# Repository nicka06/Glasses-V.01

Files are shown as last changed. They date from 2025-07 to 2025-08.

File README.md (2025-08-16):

# Glasses-V.01

This repo shows a pair of "AI" glasses that use a microphone, speaker, and microcontroller to allow users to have siri at all times (when on wifi). They'll be able to ask questions, complete tasks, and be more efficient with these glasses. While these glasses have only audio, it is a first step towareds glasses with cameras and more. This is my personal end goal for this project. Just a stepping stone towards more advance glasses work. (Hence the V0.1 repo name). If you have any questions, feel free to reach out. 

Full Glasses Screenshot
PCB Arm Screenshot
Battery Arm Screenshot
PCB Screenshot
Frame Screenshot
Screenshot 2025-08-16 at 12 45 35 PM
Screenshot 2025-08-16 at 12 45 51 PM

|Part |Part Number |# of parts|snapeda link |Price|Actual Link |Total Price|
|---|---|---|---|-----|---|---|
|Microcontroller |ESP32-S3-WROOM-1-N16R8 |1 |https://www.snapeda.com/parts/ESP32-S3-WROOM-1-N16R8/Espressif%20Systems/view-part/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 |6.56 |https://www.digikey.com/en/products/detail/espressif-systems/ESP32-S3-WROOM-1-N16R8/16163954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 |13.12 |
|Microphone |ICS-43434 |1 |https://www.snapeda.com/parts/ICS-43434/TDK%20InvenSense/view-part/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 |2.98 |https://www.digikey.com/en/products/detail/tdk-invensense/ICS-43434/6140298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 |5.96 |
|Amplifier |MAX98357AETE+T |1 |http://snapeda.com/parts/MAX98357AETE%2BT/Analog%20Devices/view-part/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 |3.19 |https://www.digikey.com/en/products/detail/analog-devices-inc-maxim-integrated/MAX98357AETE-T/4936122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 |6.38 |
|Speaker |KDMG151508-05 |1 |https://www.snapeda.com/parts/KDMG151508-05/Kingstate/view-part/?ref=search&t=KDMG151508-05 |2.12 |https://www.digikey.com/en/products/detail/db-unlimited/SM150908-2/9990586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 |4.24 |
|Battery |1570 Lithium Polymer Battery 3.7V 100mAh|1 |https://www.snapeda.com/parts/1570/Adafruit%20Industries/view-part/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 |5.95 |https://www.digikey.com/en/products/detail/adafruit-industries-llc/1570/5054546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 |11.9 |
|Charge Management Controller|MCP73831T-2ACI/OT |1 |https://www.snapeda.com/parts/MCP73831T-2ACI/OT/Microchip%20Technology/view-part/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 |0.76 |https://www.digikey.com/en/products/detail/microchip-technology/MCP73831T-2ACI-OT/964301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 |1.52 |
| |TLV62568DBVR |1 |https://www.snapeda.com/parts/2340901-1/TE%20Connectivity/view-part/?ref=search&t=2340901-1&ab_test_case=b |0.23 |https://www.digikey.com/en/products/detail/texas-instruments/TLV62568DBVR/6588886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 |0.46 |
|USB C Port |2340901-1 |1 |https://www.snapeda.com/parts/2340901-1/TE%20Connectivity/view-part/?ref=search&t=2340901-1&ab_test_case=b |0.7  |https://www.digikey.com/en/products/detail/gct/USB4500-03-0-A/15283206 |1.4 |
|Battery Connector (white) |B2B-PH-K-S (LF)(SN) |1 |https://www.snapeda.com/parts/B2B-PH-K-S%20%28LF%29%28SN%29/JST/view-part/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 |0.1  |https://www.digikey.com/en/products/detail/jst-sales-america-inc/B2B-XH-A/1651045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 |0.2 |
|Manual Switch |PCM12SMTR |1 |https://www.snapeda.com/parts/PCM12SMTR/Littelfuse%2FC%26K/view-part/?ref=search&t=PCM12SMTR&ab_test_case=b |0.8  |https://www.snapeda.com/parts/PCM12SMTR/Littelfuse%2FC%26K/view-part/?ref=search&t=PCM12SMTR&ab_test_case=b |1.6 |
|LED Blue Light |LTST-C191TBKT |1 |https://www.snapeda.com/parts/LTST-C191TBKT/Lite-On%20Electronics/view-part/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 |0.24 |https://www.digikey.com/en/products/detail/liteon/LTST-C191TBKT/388530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 |0.48 |
|LED Red Light |LTST-C191KRKT |1 |https://www.snapeda.com/parts/LTST-C191KRKT/Lite-On%20Inc./view-part/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 |0.15 |https://www.digikey.com/en/products/detail/liteon/LTST-C191KRKT/386837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 |0.3 |
|5.1k Resistor |ERA-3ARB512V |3 |https://www.snapeda.com/parts/ERA-3ARB512V/Panasonic/view-part/?ref=search&t=ERA-3ARB512V&ab_test_case=b |0.35 |https://www.digikey.com/en/products/detail/panasonic-electronic-components/ERA-3ARB512V/3073669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 |2.1 |
|10k resistor |CR0603AFX-1002EAS |2 |https://www.snapeda.com/parts/CR0603AFX-1002EAS/Bourns/view-part/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 |0.1  |https://www.digikey.com/en/products/detail/bourns-inc/CR0603AFX-1002EAS/10240117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 |0.4 |
|220hms Resistor |WK73R1JTTD2200F |2 |https://www.snapeda.com/parts/WK73R1JTTD2200F/KOA%20Speer/view-part/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 |0.12 |https://www.mouser.com/ProductDetail/KOA-Speer/WK73R1JTTD2200F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 |0.48 |
|100nf capacitor |885012206071 |4 |https://www.snapeda.com/parts/885012206071/W%C3%BCrth%20Elektronik/view-part/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 |0.1  |https://www.digikey.com/en/products/detail/w%C3%BCrth-elektronik/885012206071/5453844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 |0.8 |
|4.7u capitor |CL10A475KA8NQNC |1 |https://www.snapeda.com/parts/CL10A475KA8NQNC/Samsung/view-part/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 |0.23 |https://www.mouser.com/ProductDetail/Samsung-Electro-Mechanics/CL10A475KA8NQNC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 |0.46 |
|10uf capictor |GRM188R61A106MAALD |2 |https://www.snapeda.com/parts/GRM188R61A106MAALD/Murata/view-part/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 |0.22 |https://www.digikey.com/en/products/detail/murata-electronics/GRM188R61A106MAALD/4905335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 |0.88 |
|22uf capictor |C1608X5R0J226M080AC |1 |https://www.snapeda.com/parts/C1608X5R0J226M080AC/TDK/view-part/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 |0.27 |https://www.digikey.com/en/products/detail/tdk-corporation/C1608X5R0J226M080AC/2792254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 |0.54 |
|2.2 inductor |DFE252012F-2R2M=P2 |1 |https://www.snapeda.com/parts/DFE252012F-2R2M%3DP2/Murata/view-part/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 |0.24 |https://www.digikey.com/en/products/detail/murata-electronics/DFE252012F-2R2M-P2/5812591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 |0.48 |
|ESD Protector |TPD2E001DRLRG4 |1 |https://www.snapeda.com/parts/TPD2E001DRLRG4/Texas%20Instruments/view-part/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 |0.77 |https://www.digikey.com/en/products/detail/texas-instruments/TPD2E001DRLRG4/1907452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 |1.54 |
|1u capitor |885012206026 |1 |https://www.snapeda.com/parts/885012206026/W%C3%BCrth%20Elektronik/view-part/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 |0.27 |https://www.digikey.com/en/products/detail/w%C3%BCrth-elektronik/885012206026/5453800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 |0.54 |
|Switch Button |TL3315NF160Q |1 |https://www.snapeda.com/parts/TL3315NF160Q/E-Switch/view-part/?ref=search&t=tl3315nf160Q |0.15 |https://www.digikey.com/en/products/detail/e-switch/TL3315NF160Q/1870395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 |0.3 |
|3d Printing filament |N/A |1 |https://www.amazon.com/eSUN-Filament-Printing-Printer-Designed/dp/B0DGQBMJMK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|11.39|https://www.amazon.com/eSUN-Filament-Printing-Printer-Designed/dp/B0DGQBMJMK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|11.39 |
|PCB |N/A |1 |N/A |2 |N/A |2 |
| | | | | | |69.47 |
                                                                                                                                                                                                                                                                                    |56.08      |

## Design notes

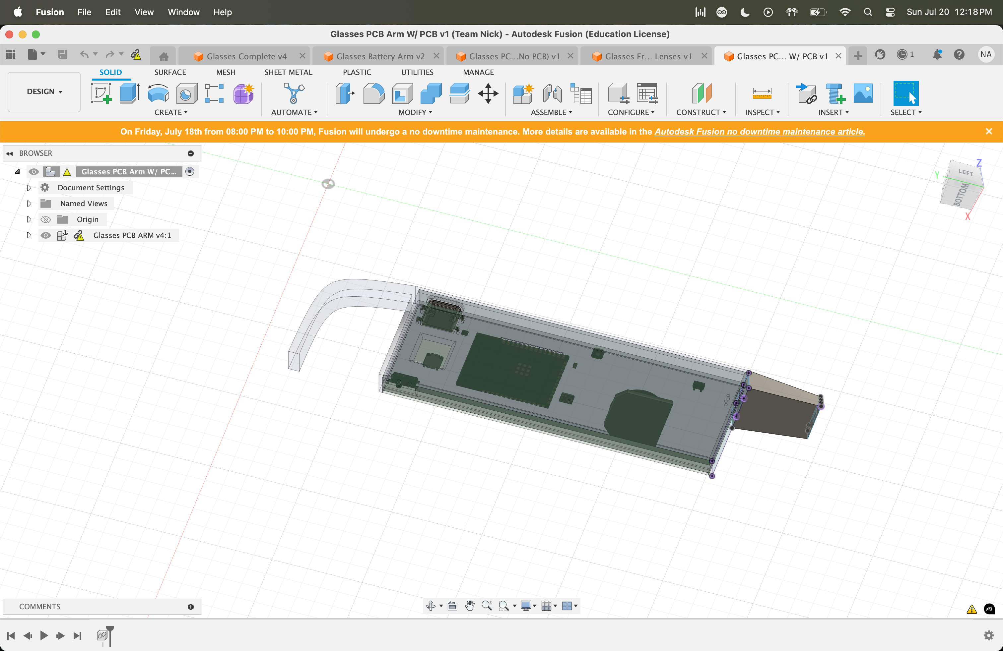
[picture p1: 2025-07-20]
production/pics/Screenshot 2025-07-20 at 12.18.14 PM.png

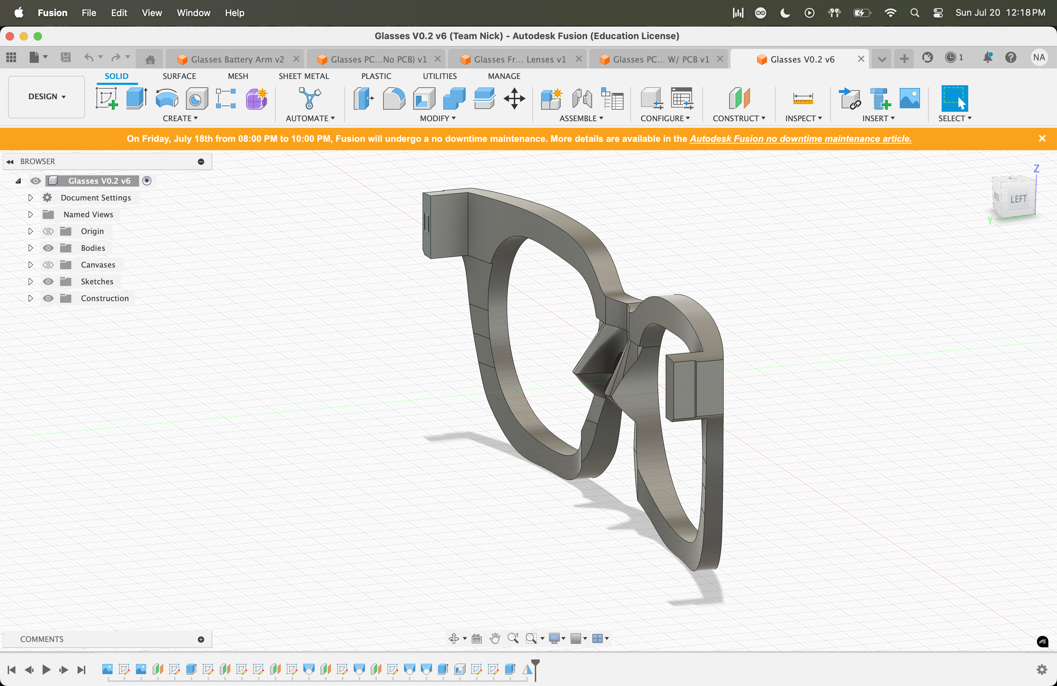
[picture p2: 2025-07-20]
production/pics/Screenshot 2025-07-20 at 12.18.28 PM.png

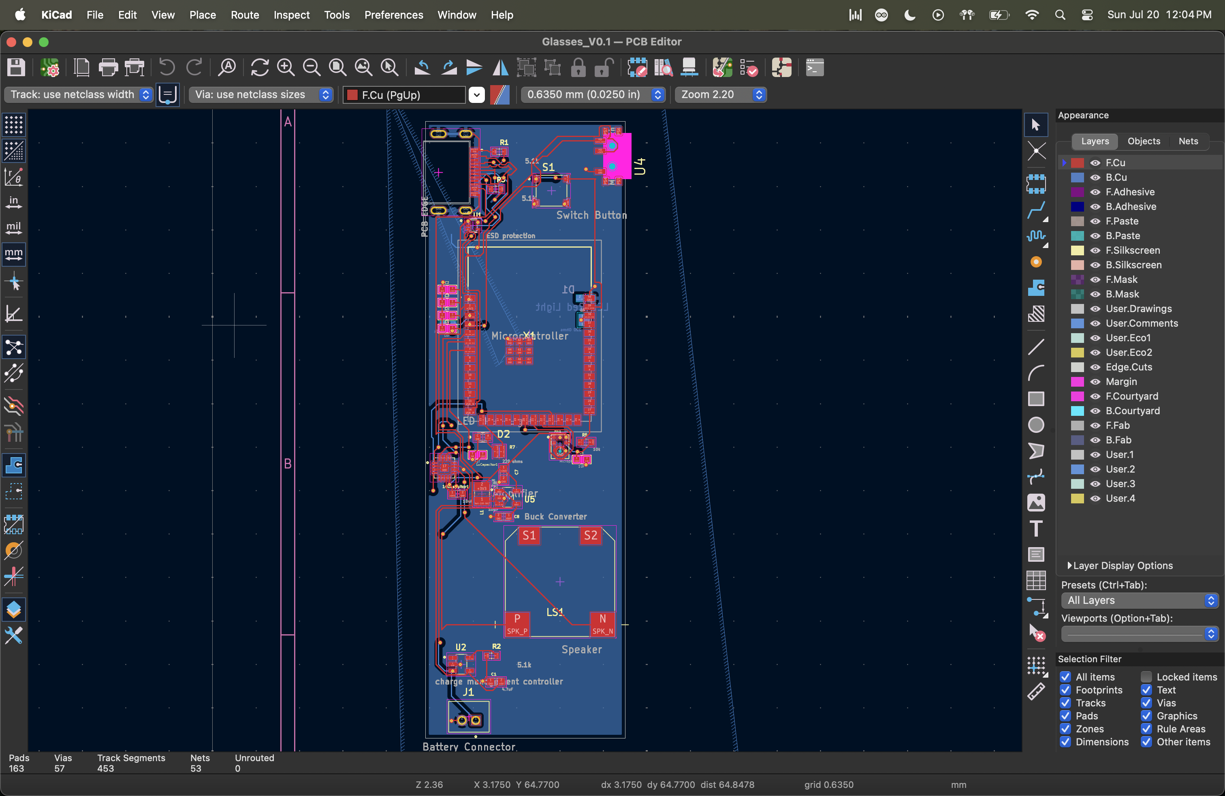
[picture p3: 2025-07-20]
production/pics/Screenshot 2025-07-20 at 12.04.41 PM.png

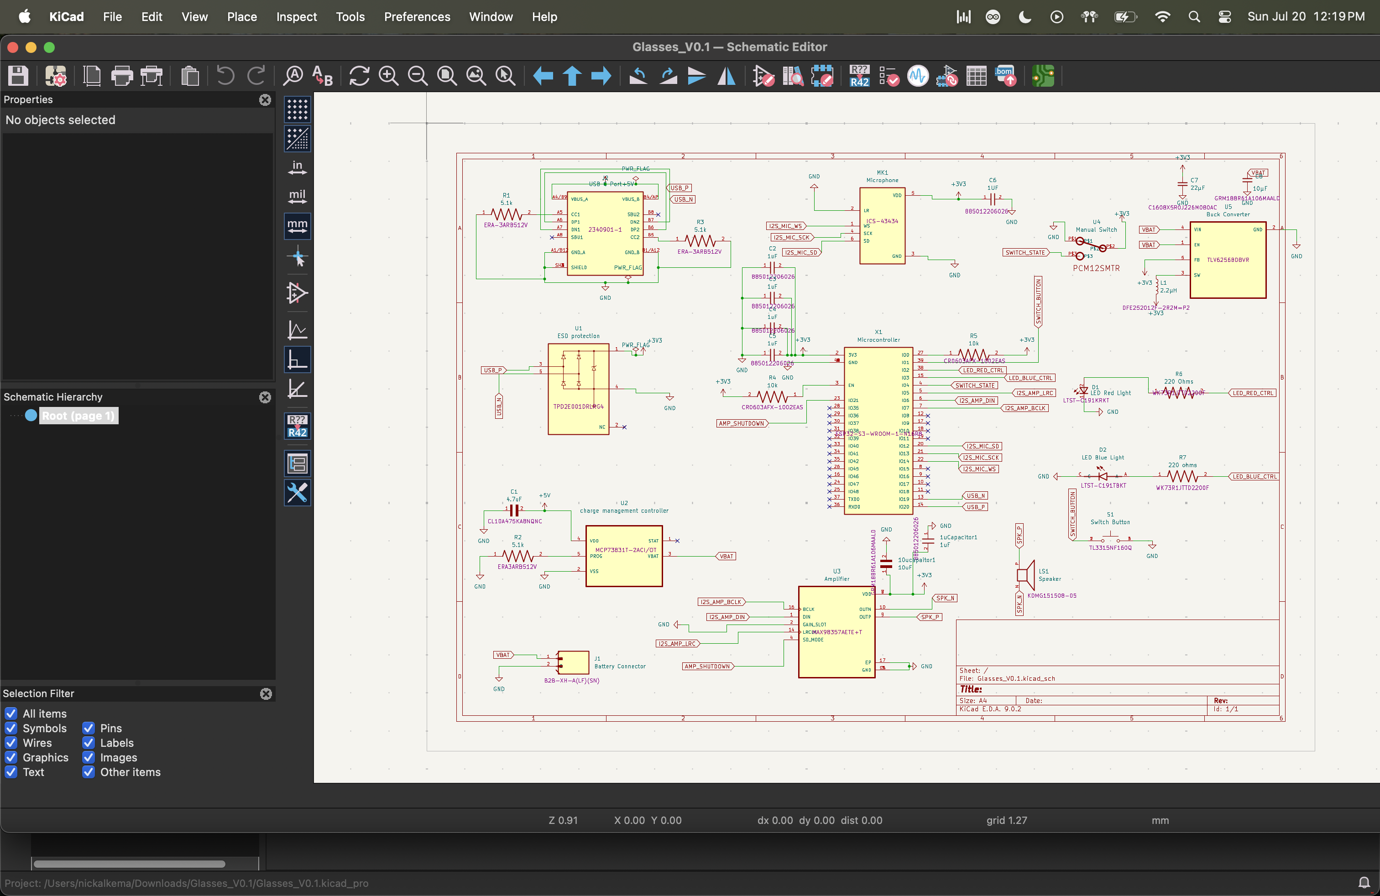
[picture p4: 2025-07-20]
production/pics/Screenshot 2025-07-20 at 12.19.34 PM.png

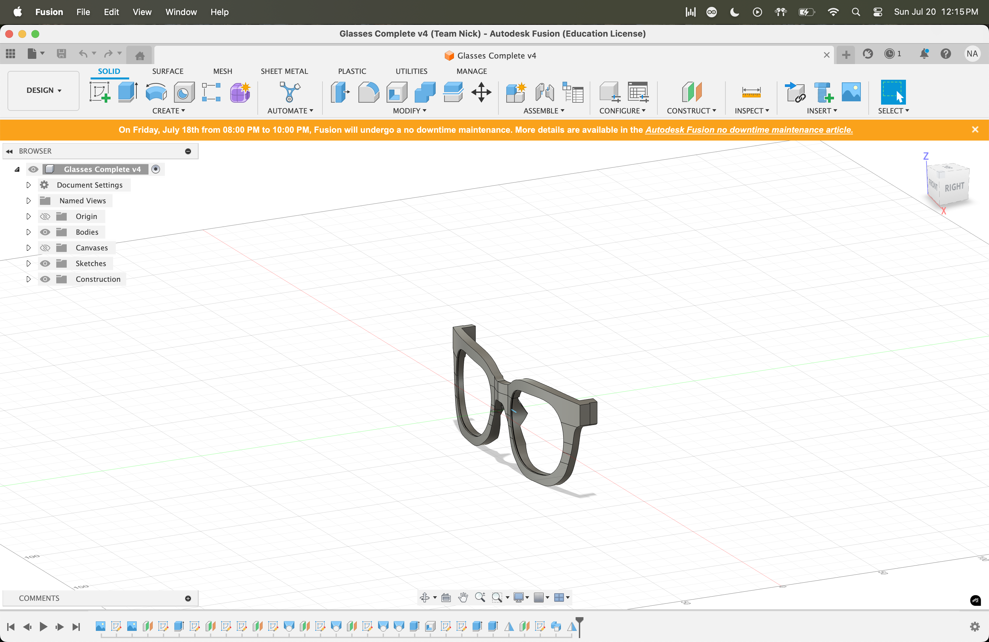
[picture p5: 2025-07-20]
production/pics/Screenshot 2025-07-20 at 12.15.24 PM.png

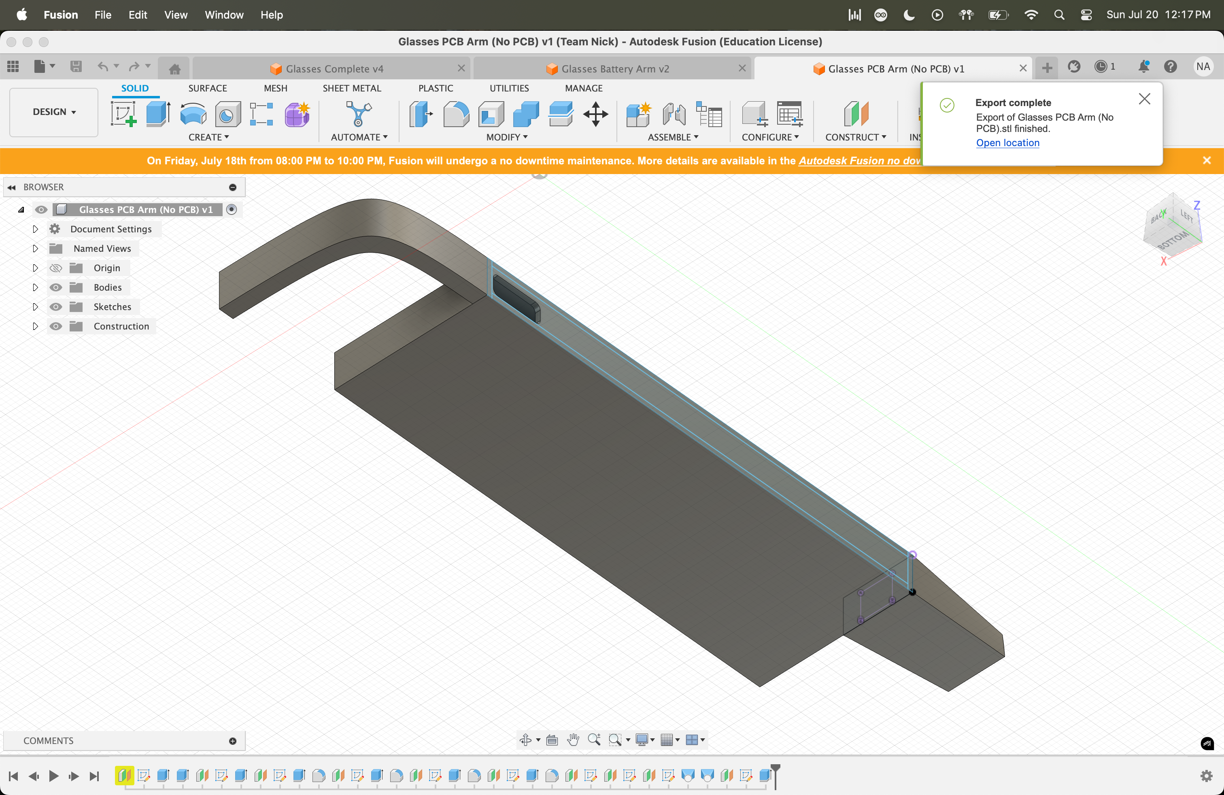
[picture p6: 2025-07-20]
production/pics/Screenshot 2025-07-20 at 12.17.30 PM.png

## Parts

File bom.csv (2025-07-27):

Part | Part Number | # of parts | snapeda link | Price | Actual Link | Total Price
Microcontroller | ESP32-S3-WROOM-1-N16R8 | 1 | https://www.snapeda.com/parts/ESP32-S3-WROOM-1-N16R8/Espressif%20Systems/view-part/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 | 6.56 | https://www.digikey.com/en/products/detail/espressif-systems/ESP32-S3-WROOM-1-N16R8/16163954?gad_source=1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 | 13.12
Microphone | ICS-43434 | 1 | https://www.snapeda.com/parts/ICS-43434/TDK%20InvenSense/view-part/?t=ICS-43434&con_ref=None | 2.98 | https://www.digikey.com/en/products/detail/tdk-invensense/ICS-43434/6140298 | 5.96
Amplifier | MAX98357AETE+T | 1 | http://snapeda.com/parts/MAX98357AETE%2BT/Analog%20Devices/view-part/?t=MAX98357AETE%2BT&ab_test_case=b | 3.19 | https://www.digikey.com/en/products/detail/analog-devices-inc-maxim-integrated/MAX98357AETE-T/4936122 | 6.38
Speaker | KDMG151508-05 | 1 | https://www.snapeda.com/parts/KDMG151508-05/Kingstate/view-part/?ref=search&t=KDMG151508-05 | 2.12 | https://www.digikey.com/en/products/detail/db-unlimited/SM150908-2/9990586?gad_source=1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 | 4.24
Battery | 1570 Lithium Polymer Battery 3.7V 100mAh | 1 | https://www.snapeda.com/parts/1570/Adafruit%20Industries/view-part/?ab_test_case=b | 5.95 | https://www.digikey.com/en/products/detail/adafruit-industries-llc/1570/5054546 | 11.9
Charge Management Controller | MCP73831T-2ACI/OT | 1 | https://www.snapeda.com/parts/MCP73831T-2ACI/OT/Microchip%20Technology/view-part/?t=MCP73831&ab_test_case=b | 0.76 | https://www.digikey.com/en/products/detail/microchip-technology/MCP73831T-2ACI-OT/964301 | 1.52
 | TLV62568DBVR | 1 | https://www.snapeda.com/parts/2340901-1/TE%20Connectivity/view-part/?t=2340901-1&ab_test_case=b | 0.23 | https://www.digikey.com/en/products/detail/texas-instruments/TLV62568DBVR/6588886 | 0.46
USB C Port | 2340901-1 | 1 | https://www.snapeda.com/parts/2340901-1/TE%20Connectivity/view-part/?t=2340901-1&ab_test_case=b | 0.7 | https://www.digikey.com/en/products/detail/gct/USB4500-03-0-A/15283206 | 1.4
Battery Connector (white) | B2B-PH-K-S (LF)(SN) | 1 | https://www.snapeda.com/parts/B2B-PH-K-S%20%28LF%29%28SN%29/JST/view-part/?t=B2B-PH-K-S&ab_test_case=b | 0.1 | https://www.digikey.com/en/products/detail/jst-sales-america-inc/B2B-XH-A/1651045?gad_source=1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 | 0.2
Manual Switch | PCM12SMTR | 1 | https://www.snapeda.com/parts/PCM12SMTR/Littelfuse%2FC%26K/view-part/?t=PCM12SMTR&ab_test_case=b | 0.8 | https://www.snapeda.com/parts/PCM12SMTR/Littelfuse%2FC%26K/view-part/?t=PCM12SMTR&ab_test_case=b | 1.6
LED Blue Light | LTST-C191TBKT | 1 | https://www.snapeda.com/parts/LTST-C191TBKT/Lite-On%20Electronics/view-part/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 | 0.24 | https://www.digikey.com/en/products/detail/liteon/LTST-C191TBKT/388530 | 0.48
LED Red Light | LTST-C191KRKT | 1 | https://www.snapeda.com/parts/LTST-C191KRKT/Lite-On%20Inc./view-part/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 | 0.15 | https://www.digikey.com/en/products/detail/liteon/LTST-C191KRKT/386837 | 0.3
5.1k Resistor | ERA-3ARB512V | 3 | https://www.snapeda.com/parts/ERA-3ARB512V/Panasonic/view-part/?t=ERA-3ARB512V&ab_test_case=b | 0.35 | https://www.digikey.com/en/products/detail/panasonic-electronic-components/ERA-3ARB512V/3073669 | 2.1
10k resistor | CR0603AFX-1002EAS | 2 | https://www.snapeda.com/parts/CR0603AFX-1002EAS/Bourns/view-part/?t=CR0603AFX-1002EAS&ab_test_case=b | 0.1 | https://www.digikey.com/en/products/detail/bourns-inc/CR0603AFX-1002EAS/10240117 | 0.4
220hms Resistor | WK73R1JTTD2200F | 2 | https://www.snapeda.com/parts/WK73R1JTTD2200F/KOA%20Speer/view-part/?t=WK73R1JTTD2200F&ab_test_case=b | 0.12 | https://www.mouser.com/ProductDetail/KOA-Speer/WK73R1JTTD2200F?qs=xhbEVWpZdWcwQMv%2FxntCbQ%3D%3D | 0.48
100nf capacitor | 885012206071 | 4 | https://www.snapeda.com/parts/885012206071/W%C3%BCrth%20Elektronik/view-part/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 | 0.1 | https://www.digikey.com/en/products/detail/w%C3%BCrth-elektronik/885012206071/5453844 | 0.8
4.7u capitor | CL10A475KA8NQNC | 1 | https://www.snapeda.com/parts/CL10A475KA8NQNC/Samsung/view-part/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 | 0.23 | https://www.mouser.com/ProductDetail/Samsung-Electro-Mechanics/CL10A475KA8NQNC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 | 0.46
10uf capictor | GRM188R61A106MAALD | 2 | https://www.snapeda.com/parts/GRM188R61A106MAALD/Murata/view-part/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 | 0.22 | https://www.digikey.com/en/products/detail/murata-electronics/GRM188R61A106MAALD/4905335 | 0.88
22uf capictor | C1608X5R0J226M080AC | 1 | https://www.snapeda.com/parts/C1608X5R0J226M080AC/TDK/view-part/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 | 0.27 | https://www.digikey.com/en/products/detail/tdk-corporation/C1608X5R0J226M080AC/2792254 | 0.54
2.2 inductor | DFE252012F-2R2M=P2 | 1 | https://www.snapeda.com/parts/DFE252012F-2R2M%3DP2/Murata/view-part/?t=DFE252012F-2R2M%3DP2&ab_test_case=b | 0.24 | https://www.digikey.com/en/products/detail/murata-electronics/DFE252012F-2R2M-P2/5812591 | 0.48
ESD Protector | TPD2E001DRLRG4 | 1 | https://www.snapeda.com/parts/TPD2E001DRLRG4/Texas%20Instruments/view-part/?t=TPD2E001DRLR&ab_test_case=b | 0.77 | https://www.digikey.com/en/products/detail/texas-instruments/TPD2E001DRLRG4/1907452 | 1.54
1u capitor | 885012206026 | 1 | https://www.snapeda.com/parts/885012206026/W%C3%BCrth%20Elektronik/view-part/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 | 0.27 | https://www.digikey.com/en/products/detail/w%C3%BCrth-elektronik/885012206026/5453800 | 0.54
Switch Button | TL3315NF160Q | 1 | https://www.snapeda.com/parts/TL3315NF160Q/E-Switch/view-part/?ref=search&t=tl3315nf160Q | 0.15 | https://www.digikey.com/en/products/detail/e-switch/TL3315NF160Q/1870395 | 0.3
 |  |  |  |  |  | 56.08

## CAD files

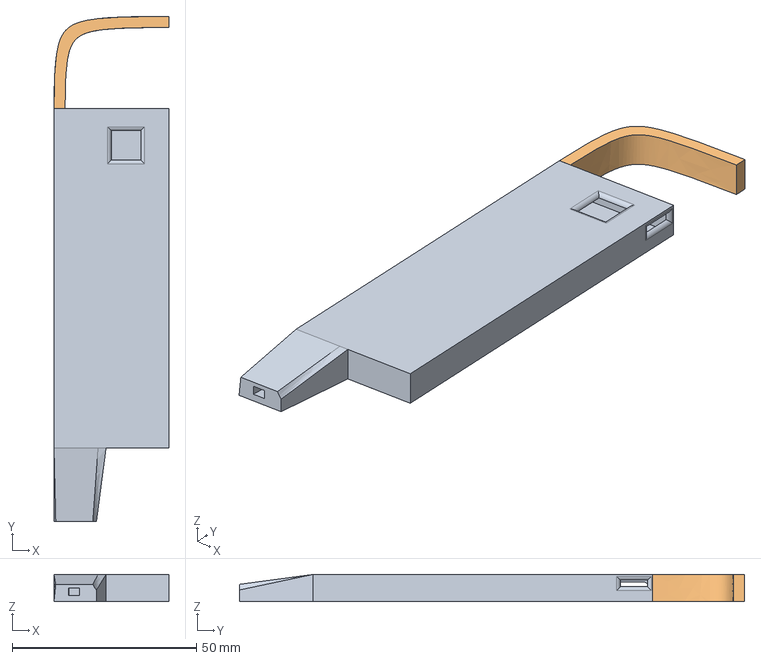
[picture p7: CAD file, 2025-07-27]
cad/Glasses PCB Arm (No PCB) v1.step
31.2 x 137.2 x 7.35 mm

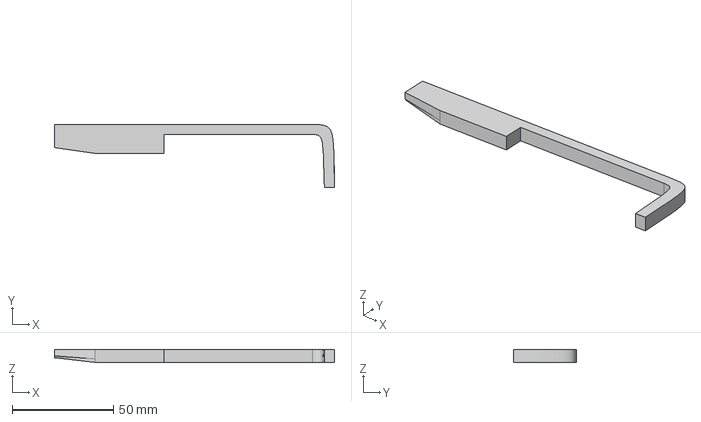
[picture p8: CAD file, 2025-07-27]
cad/Glasses Battery Arm v2.step
138.2 x 31.2 x 6.30 mm

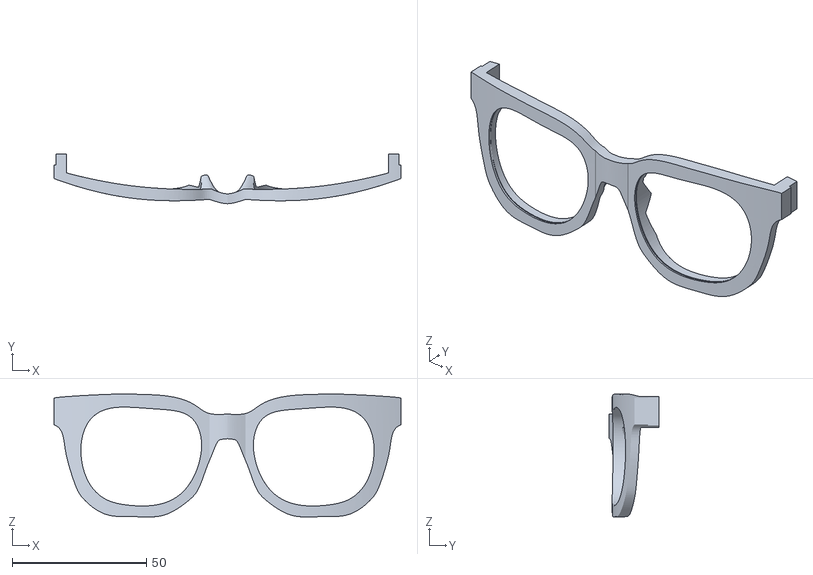
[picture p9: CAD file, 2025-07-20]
production/cad/Glasses Frames.stl
129.5 x 18.5 x 45.9

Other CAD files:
production/cad/Glasses PCB Arm (No PCB).stl
production/cad/Glasses Battery Arm.stl

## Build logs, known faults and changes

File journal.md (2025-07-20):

title: "Audio Glasses"

author: "Nick"

description: "Smart glasses that connect to wifi and allow you to essentially use smart siri on your glasses"

created_at: "2024-07-18"

Time Spent: 30 ish hours (maybe more tbh if you consider research as this was one of my first hardware projects ever)

7/18/2025

--Unforunately, I did not read through the requirements and only sumbitted a hackpad thus far which led me to believe there was no journal portion. Thus, when I'm nearing the end of the project, I finally decide to make the journal. 
Although this is a bit disappointing, I'll do my best to recall what I have done thus far and lay it out in chronolocial order. Then, I'll add my future journals here as well. 

Beginning: (10 ish hours)

I started off this project by consulting with chatgpt on a parts list. It started off with a fairly comprehensive list of things that I'll need. Then, I went into snapeda the online website to browse all the parts. This was about a days worth
of work. I know it seems like not that much but this is my "first" hardware project (besides the hackpad that I did which was basically laid out for me in a step by step guide). Also as a side note, beginner projects are so important because I 
don't feel like I could have done any of this without that beginner project.

The next thing I started to do was lay out the schematic. Again, a lot of time was spent consulting with google, the datasheets, and google. It took a lot of finesse and mind numbing work but I was eventually able to get it.
I would estimate just this process took quite a while. It's worth mentioning that I spent a decent chunk of time assembling and modifying the symbols. They were very finicky. The footprint's were also a pain to do.

Middle: (another 8 ish hours)

Once I completed the schematic, I began working on the actual pcb design which was a HUGE pain. I learned that making small pcbs is not a fun process at all. Additioanlly, it was my first time doing it all by myself so add that to the 
mix and I was in for a disaster. I had to restart 3-4 times and it probably took 3-4 days in total to actually get it done. 

Finish Line: ( 12 ish hours)

Finally, I began working on the cad part of the project. In my opinion, this was the part of the project that I had the most fun with. The first thing that I did was download some images of photos, looked up the
size of a typical glasses frame, and then I started to sketch out the outline of the glasses frame. I continued to do this until I was able to complete the glasses frame (with the inside of the glasses hollowed
out for the wires to run through the frames). Once I finished that, I began working on the sides of the frames. The sides were finicky as well as I had to first model around the pcb/battery and then actually create 
the strucuture of glasses. It's worth acknowledging that in this iteration, I made the glasses fit around teh hardware if that makes sense. (So the glasses shape/fit will almost certainly not be ideal. It's my goal 
that when I begin working on this project next time, I do the opposite. I start with a really nice frame and shape for glasses and then work on the hardware to make it fit within the nice frame and size. Now, what I have
left to do as I'm writing this is to upload all of the information to the github, spend some time to slice some of the hardware so that I can assemble it once I get the components and then begin working on the firmware tommorow. 
I have a feeling that the firmware won't be that bad (famous last words). In any case, I'll give that a shot and upload all of that information tomorrow. (Also for the images, I'll post those all at the end). 

7/18/2025 (1.5 hours)

Today, I continued to look through the work that I've done this far to confirm what I wanted to do with the firmware exactly. I came up with teh exact processes that I wanted to use and now that I have that, I started to work on the firmware. Tomorrow, I'll finish the rest of the firmware and submit the project.

7/19/2025 (2-3 hrs)

Today I worked on the firmware and completed that. Then, I started to build out the repository to have all of the information and content that I've been working on for the last few weeks be displayed in this repo. That way, I'd be able to submit to highway later in the day.

Screenshot 2025-07-20 at 12 04 41 PM
Screenshot 2025-07-20 at 12 15 24 PM
Screenshot 2025-07-20 at 12 17 02 PM
Screenshot 2025-07-20 at 12 17 30 PM
Screenshot 2025-07-20 at 12 17 45 PM
Screenshot 2025-07-20 at 12 18 14 PM
Screenshot 2025-07-20 at 12 18 28 PM
Screenshot 2025-07-20 at 12 19 34 PM

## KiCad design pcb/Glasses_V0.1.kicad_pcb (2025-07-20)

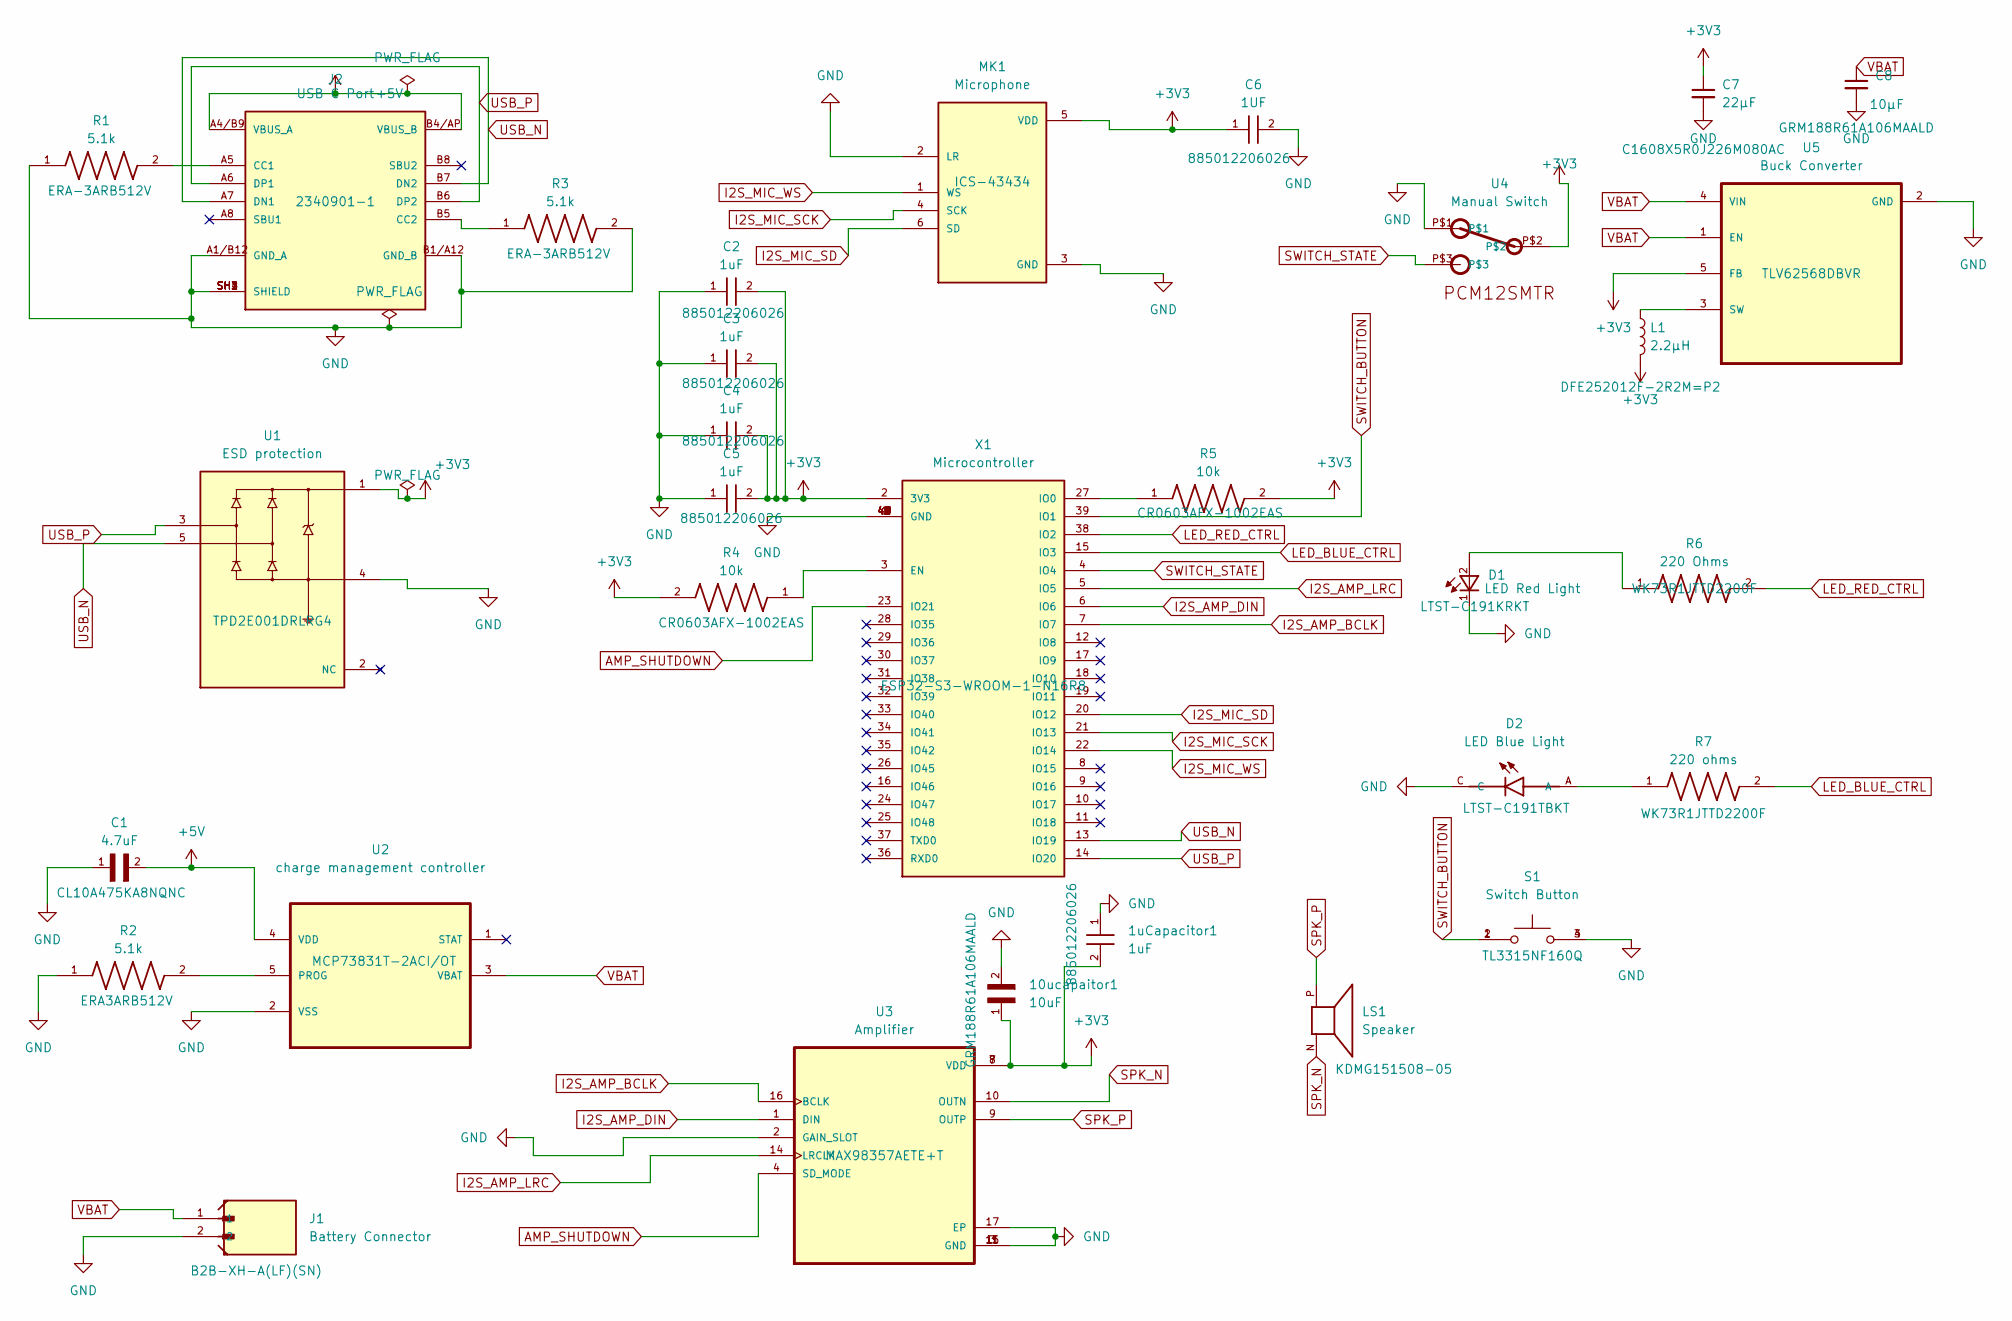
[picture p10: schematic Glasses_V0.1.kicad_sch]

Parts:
1uCapacitor1: 1uF; WCAP-CSGP_0603_R
10ucapaitor1: 10uF; CAPC1608X95N; DigiKey_Part_Number 490-12734-2-ND
C1: 4.7uF; CAPC1608X100N
C2, C3, C4, C5: 1uF; WCAP-CSGP_0603_R
C6: 1UF; WCAP-CSGP_0603_R
C7: 22µF; CAPC1608X100N
C8: 10µF; CAPC1608X95N
D1: LED Red Light; 0603; DigiKey_Part_Number 160-1447-2-ND
D2: LED Blue Light; LEDC1608X65N; DigiKey_Part_Number 160-1647-2-ND
J1: Battery Connector; JST_B2B-PH-K-S_LF__SN_
J2: USB C Port; TE_2340901-1; PARTREV A
L1: 2.2µH; INDC2520X120N
LS1: Speaker; SPKR_KDMG151508-05; PARTREV 1.1
MK1: Microphone; MIC_ICS-43434
R1, R2, R3: 5.1k; RES_ERA3ARB512V; PARTREV 3/1/2020
R4, R5: 10k; RESC1608X55N
R6: 220 Ohms; RESC0816X55N
R7: 220 ohms; RESC0816X55N
S1: Switch Button; SW_TL3315NF160Q; PARTREV B
U1: ESD protection; SOTFL50P160X60-5N; PARTREV I
U2: charge management controller; SOT95P280X145-5N; MPN MCP73831T-2ACI/OT
U3: Amplifier; QFN50P300X300X80-17N
U4: Manual Switch; PCM12SMTR
U5: Buck Converter; SOT95P280X145-5N
X1: Microcontroller; ESP32S3WROOM1N8R2; MANUFACTURER_PART_NUMBER ESP32-S3-WROOM-1-N16R8

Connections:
+3V3: 1uCapacitor1.2, 10ucapaitor1.1, C2.2, C3.2, C4.2, C5.2, C6.1, C7.1, L1.2, MK1.5 (VDD), R4.2, R5.2, U1.1, U3.7 (VDD), U3.8 (VDD), U4.P$2, U5.5 (FB), X1.2 (3V3)
+5V: C1.2, J2.A4/B9 (VBUS_A), J2.B4/AP (VBUS_B), U2.4 (VDD)
AMP_SHUTDOWN: U3.4 (SD_MODE), X1.23 (IO21)
GND: 1uCapacitor1.1, 10ucapaitor1.2, C1.1, C2.1, C3.1, C4.1, C5.1, C6.2, C7.2, C8.2, D1.1, D2.C, J1.2, J2.A1/B12 (GND_A), J2.B1/A12 (GND_B), J2.SH1 (SHIELD), J2.SH2 (SHIELD), J2.SH3 (SHIELD), J2.SH4 (SHIELD), MK1.2 (LR), MK1.3 (GND), R1.1, R2.1, R3.2, S1.3, S1.4, U1.4, U2.2 (VSS), U3.2 (GAIN_SLOT), U3.3 (GND), U3.11 (GND), U3.15 (GND), U3.17 (EP), U4.P$1, U5.2 (GND), X1.1 (GND), X1.40 (GND), X1.41 (GND), X1.42 (GND), X1.43 (GND), X1.44 (GND), X1.45 (GND), X1.46 (GND), X1.47 (GND), X1.48 (GND), X1.49 (GND)
I2S_AMP_BCLK: U3.16 (BCLK), X1.7 (IO7)
I2S_AMP_DIN: U3.1 (DIN), X1.6 (IO6)
I2S_AMP_LRC: U3.14 (LRCLK), X1.5 (IO5)
I2S_MIC_SCK: MK1.4 (SCK), X1.21 (IO13)
I2S_MIC_SD: MK1.6 (SD), X1.20 (IO12)
I2S_MIC_WS: MK1.1 (WS), X1.22 (IO14)
LED_BLUE_CTRL: R7.2, X1.15 (IO3)
LED_RED_CTRL: R6.2, X1.38 (IO2)
unnamed: D1.2, R6.1
unnamed: D2.A, R7.1
unnamed: J2.A5 (CC1), R1.2
unnamed: J2.B5 (CC2), R3.1
unnamed: R2.2, U2.5 (PROG)
unnamed: L1.1, U5.3 (SW)
unnamed: R4.1, X1.3 (EN)
unnamed: R5.1, X1.27 (IO0)
SPK_N: LS1.N, U3.10 (OUTN)
SPK_P: LS1.P, U3.9 (OUTP)
SWITCH_BUTTON: S1.1, S1.2, X1.39 (IO1)
SWITCH_STATE: U4.P$3, X1.4 (IO4)
USB_N: J2.A7 (DN1), J2.B7 (DN2), U1.5, X1.13 (IO19)
USB_P: J2.A6 (DP1), J2.B6 (DP2), U1.3, X1.14 (IO20)
VBAT: C8.1, J1.1, U2.3 (VBAT), U5.1 (EN), U5.4 (VIN)

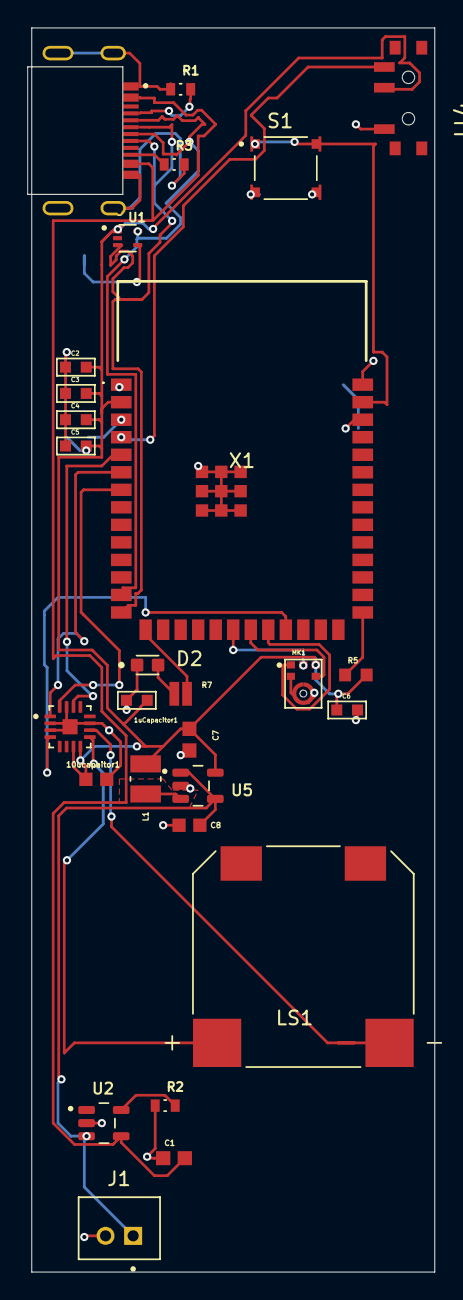
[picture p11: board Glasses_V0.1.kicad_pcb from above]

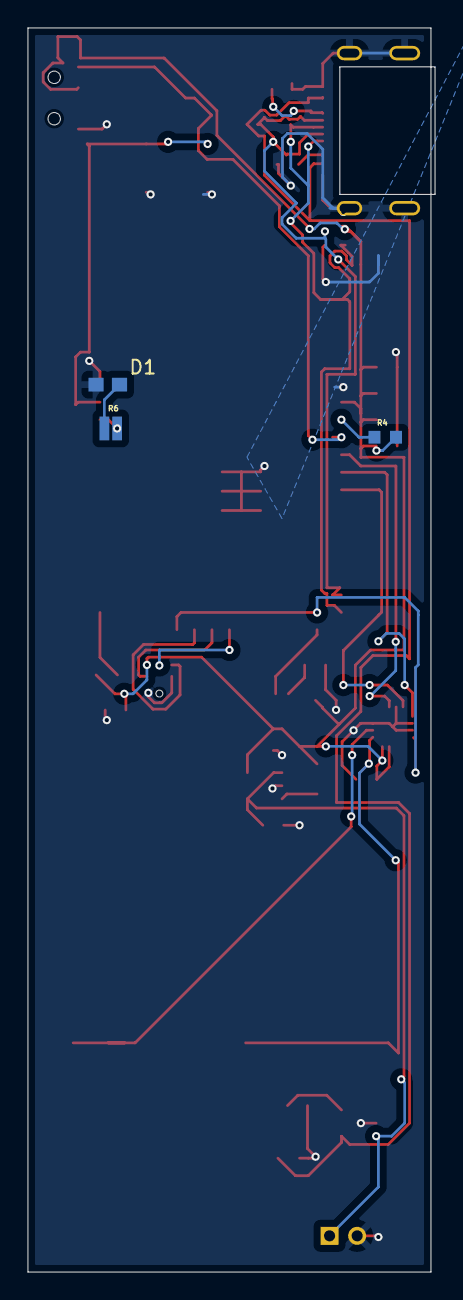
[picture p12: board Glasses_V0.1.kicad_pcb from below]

Board: 2 copper layers, 29.2 x 90.2 mm, 31 parts (3 on the bottom side), 27 nets.

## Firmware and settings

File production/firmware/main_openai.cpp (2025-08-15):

#include <Arduino.h>
#include "hardware_pins.h"
#include <WiFi.h>
#include <HTTPClient.h>
#include <ArduinoJson.h>
#include "driver/i2s.h"
#include <base64.h>

// --- WiFi Configuration ---
const char* ssid = "YOUR_WIFI_SSID";
const char* password = "YOUR_WIFI_PASSWORD";

// --- OpenAI Configuration ---
const char* openai_api_key = "YOUR_OPENAI_API_KEY";
const char* openai_whisper_url = "https://api.openai.com/v1/audio/transcriptions";
const char* openai_chat_url = "https://api.openai.com/v1/chat/completions";
const char* openai_tts_url = "https://api.openai.com/v1/audio/speech";

// --- Audio Configuration ---
#define I2S_MIC_PORT I2S_NUM_0
#define I2S_SPEAKER_PORT I2S_NUM_1
const int SAMPLE_RATE = 16000;
const int BITS_PER_SAMPLE = 16;
const int AUDIO_BUFFER_SIZE = 1024;

// --- State Management ---
bool is_recording = false;
bool is_processing = false;
std::vector<int16_t> audio_recording;

void setup() {
  Serial.begin(115200);
  Serial.println("Booting up AI Glasses...");

  // Configure pins
  pinMode(LED_BLUE_PIN, OUTPUT);
  pinMode(AMP_SHUTDOWN_PIN, OUTPUT);
  pinMode(SWITCH_BUTTON_PIN, INPUT_PULLUP);
  
  digitalWrite(AMP_SHUTDOWN_PIN, LOW);
  digitalWrite(LED_BLUE_PIN, LOW);

  // Connect to WiFi
  setup_wifi();
  
  // Setup audio
  setup_i2s_microphone();
  setup_i2s_speaker();

  Serial.println("Ready for voice commands!");
}

void loop() {
  handle_voice_command();
  delay(10);
}

void handle_voice_command() {
  // Start recording when button pressed
  if (digitalRead(SWITCH_BUTTON_PIN) == LOW && !is_recording && !is_processing) {
    start_recording();
  }
  
  // Stop recording when button released
  if (digitalRead(SWITCH_BUTTON_PIN) == HIGH && is_recording) {
    stop_recording_and_process();
  }
  
  // Continue recording while button held
  if (is_recording) {
    record_audio_chunk();
  }
}

void start_recording() {
  Serial.println("🎤 Started recording...");
  digitalWrite(LED_BLUE_PIN, HIGH);
  is_recording = true;
  audio_recording.clear();
}

void record_audio_chunk() {
  int32_t raw_buffer[AUDIO_BUFFER_SIZE];
  size_t bytes_read = 0;
  
  i2s_read(I2S_MIC_PORT, raw_buffer, sizeof(raw_buffer), &bytes_read, 0);
  
  if (bytes_read > 0) {
    for (int i = 0; i < bytes_read / 4; i++) {
      audio_recording.push_back((int16_t)(raw_buffer[i] >> 16));
    }
  }
}

void stop_recording_and_process() {
  Serial.println("🛑 Stopped recording, processing...");
  digitalWrite(LED_BLUE_PIN, LOW);
  is_recording = false;
  is_processing = true;
  
  if (audio_recording.size() > 0) {
    process_voice_command();
  }
  
  is_processing = false;
}

void process_voice_command() {
  // Step 1: Convert speech to text using Whisper API
  String user_text = speech_to_text();
  if (user_text.length() == 0) return;
  
  // Step 2: Get AI response using ChatGPT API
  String ai_response = get_ai_response(user_text);
  if (ai_response.length() == 0) return;
  
  Serial.println(ai_response);
  
  // Step 3: Convert response to speech and play
  text_to_speech_and_play(ai_response);
}

String speech_to_text() {
  HTTPClient http;
  http.begin(openai_whisper_url);
  http.addHeader("Authorization", "Bearer " + String(openai_api_key));
  http.addHeader("Content-Type", "multipart/form-data; boundary=----WebKitFormBoundary7MA4YWxkTrZu0gW");
  
  // Create WAV file in memory
  String wav_data = create_wav_from_audio();
  String base64_audio = base64::encode((uint8_t*)wav_data.c_str(), wav_data.length());
  
  // Create multipart form data
  String body = "------WebKitFormBoundary7MA4YWxkTrZu0gW\r\n";
  body += "Content-Disposition: form-data; name=\"file\"; filename=\"audio.wav\"\r\n";
  body += "Content-Type: audio/wav\r\n\r\n";
  body += wav_data + "\r\n";
  body += "------WebKitFormBoundary7MA4YWxkTrZu0gW\r\n";
  body += "Content-Disposition: form-data; name=\"model\"\r\n\r\n";
  body += "whisper-1\r\n";
  body += "------WebKitFormBoundary7MA4YWxkTrZu0gW--\r\n";
  
  int httpResponseCode = http.POST(body);
  String response = "";
  
  if (httpResponseCode == 200) {
    response = http.getString();
    DynamicJsonDocument doc(1024);
    deserializeJson(doc, response);
    response = doc["text"].as<String>();
  }
  
  http.end();
  return response;
}

String get_ai_response(String user_text) {
  HTTPClient http;
  http.begin(openai_chat_url);
  http.addHeader("Authorization", "Bearer " + String(openai_api_key));
  http.addHeader("Content-Type", "application/json");
  
  DynamicJsonDocument request(1024);
  request["model"] = "gpt-3.5-turbo";
  request["messages"][0]["role"] = "user";
  request["messages"][0]["content"] = user_text;
  request["max_tokens"] = 150;
  
  String requestBody;
  serializeJson(request, requestBody);
  
  int httpResponseCode = http.POST(requestBody);
  String response = "";
  
  if (httpResponseCode == 200) {
    String jsonResponse = http.getString();
    DynamicJsonDocument doc(2048);
    deserializeJson(doc, jsonResponse);
    response = doc["choices"][0]["message"]["content"].as<String>();
  }
  
  http.end();
  return response;
}

void text_to_speech_and_play(String text) {
  HTTPClient http;
  http.begin(openai_tts_url);
  http.addHeader("Authorization", "Bearer " + String(openai_api_key));
  http.addHeader("Content-Type", "application/json");
  
  DynamicJsonDocument request(512);
  request["model"] = "tts-1";
  request["input"] = text;
  request["voice"] = "alloy";
  request["response_format"] = "wav";
  
  String requestBody;
  serializeJson(request, requestBody);
  
  int httpResponseCode = http.POST(requestBody);
  
  if (httpResponseCode == 200) {
    // Get audio data and play it
    WiFiClient* stream = http.getStreamPtr();
    play_audio_stream(stream);
  }
  
  http.end();
}

void play_audio_stream(WiFiClient* stream) {
  digitalWrite(AMP_SHUTDOWN_PIN, HIGH); // Turn on amplifier
  
  uint8_t buffer[1024];
  size_t bytes_written;
  
  while (stream->available()) {
    int bytes_read = stream->readBytes(buffer, sizeof(buffer));
    if (bytes_read > 0) {
      i2s_write(I2S_SPEAKER_PORT, buffer, bytes_read, &bytes_written, portMAX_DELAY);
    }
  }
  
  delay(100);
  digitalWrite(AMP_SHUTDOWN_PIN, LOW); // Turn off amplifier
}

String create_wav_from_audio() {
  // Simple WAV header creation
  int data_size = audio_recording.size() * 2;
  int file_size = data_size + 36;
  
  String wav = "";
  wav += "RIFF";
  wav += (char)(file_size & 0xFF);
  wav += (char)((file_size >> 8) & 0xFF);
  wav += (char)((file_size >> 16) & 0xFF);
  wav += (char)((file_size >> 24) & 0xFF);
  wav += "WAVE";
  wav += "fmt ";
  wav += (char)16; wav += (char)0; wav += (char)0; wav += (char)0; // fmt chunk size
  wav += (char)1; wav += (char)0; // PCM format
  wav += (char)1; wav += (char)0; // mono
  wav += (char)(SAMPLE_RATE & 0xFF); wav += (char)((SAMPLE_RATE >> 8) & 0xFF);
  wav += (char)((SAMPLE_RATE >> 16) & 0xFF); wav += (char)((SAMPLE_RATE >> 24) & 0xFF);
  wav += (char)((SAMPLE_RATE * 2) & 0xFF); wav += (char)(((SAMPLE_RATE * 2) >> 8) & 0xFF);
  wav += (char)(((SAMPLE_RATE * 2) >> 16) & 0xFF); wav += (char)(((SAMPLE_RATE * 2) >> 24) & 0xFF);
  wav += (char)2; wav += (char)0; // block align
  wav += (char)16; wav += (char)0; // bits per sample
  wav += "data";
  wav += (char)(data_size & 0xFF);
  wav += (char)((data_size >> 8) & 0xFF);
  wav += (char)((data_size >> 16) & 0xFF);
  wav += (char)((data_size >> 24) & 0xFF);
  
  // Add audio data
  for (int16_t sample : audio_recording) {
    wav += (char)(sample & 0xFF);
    wav += (char)((sample >> 8) & 0xFF);
  }
  
  return wav;
}

void setup_wifi() {
  WiFi.begin(ssid, password);
  while (WiFi.status() != WL_CONNECTED) {
    delay(500);
    Serial.print(".");
  }
  Serial.println("\nWiFi connected!");
}

void setup_i2s_microphone() {
  i2s_config_t i2s_mic_config = {
    .mode = (i2s_mode_t)(I2S_MODE_MASTER | I2S_MODE_RX),
    .sample_rate = SAMPLE_RATE,
    .bits_per_sample = I2S_BITS_PER_SAMPLE_32BIT,
    .channel_format = I2S_CHANNEL_FMT_RIGHT_LEFT,
    .communication_format = I2S_COMM_FORMAT_STAND_I2S,
    .intr_alloc_flags = ESP_INTR_FLAG_LEVEL1,
    .dma_buf_count = 8,
    .dma_buf_len = 64,
    .use_apll = false,
    .tx_desc_auto_clear = false,
    .fixed_mclk = 0
  };

  i2s_pin_config_t i2s_mic_pins = {
    .bck_io_num = I2S_MIC_SCK_PIN,
    .ws_io_num = I2S_MIC_WS_PIN,
    .data_out_num = I2S_PIN_NO_CHANGE,
    .data_in_num = I2S_MIC_SD_PIN
  };

  i2s_driver_install(I2S_MIC_PORT, &i2s_mic_config, 0, NULL);
  i2s_set_pin(I2S_MIC_PORT, &i2s_mic_pins);
  i2s_set_clk(I2S_MIC_PORT, SAMPLE_RATE, I2S_BITS_PER_SAMPLE_32BIT, I2S_CHANNEL_MONO);
}

void setup_i2s_speaker() {
  i2s_config_t i2s_speaker_config = {
    .mode = (i2s_mode_t)(I2S_MODE_MASTER | I2S_MODE_TX),
    .sample_rate = SAMPLE_RATE,
    .bits_per_sample = (i2s_bits_per_sample_t)BITS_PER_SAMPLE,
    .channel_format = I2S_CHANNEL_FMT_RIGHT_LEFT,
    .communication_format = I2S_COMM_FORMAT_STAND_I2S,
    .intr_alloc_flags = ESP_INTR_FLAG_LEVEL1,
    .dma_buf_count = 8,
    .dma_buf_len = 64,
    .use_apll = false,
    .tx_desc_auto_clear = true,
    .fixed_mclk = 0
  };

  i2s_pin_config_t i2s_speaker_pins = {
    .bck_io_num = I2S_AMP_BCLK_PIN,
    .ws_io_num = I2S_AMP_LRC_PIN,
    .data_out_num = I2S_AMP_DIN_PIN,
    .data_in_num = I2S_PIN_NO_CHANGE
  };

  i2s_driver_install(I2S_SPEAKER_PORT, &i2s_speaker_config, 0, NULL);
  i2s_set_pin(I2S_SPEAKER_PORT, &i2s_speaker_pins);
}

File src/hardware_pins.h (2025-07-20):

#pragma once // Prevents the file from being included multiple times

// --- LED Pins ---
const int LED_RED_PIN = 38;
const int LED_BLUE_PIN = 15;

// --- Switch & Button Pins ---
const int SWITCH_STATE_PIN = 4;   // Manual slide switch
const int SWITCH_BUTTON_PIN = 39;  // Momentary push button

// --- Amplifier (Speaker) Pins ---
const int AMP_SHUTDOWN_PIN = 23;
// I2S is a protocol for audio
const int I2S_AMP_BCLK_PIN = 7;  // Bit Clock
const int I2S_AMP_LRC_PIN = 5;   // Left/Right Clock (Word Select)
const int I2S_AMP_DIN_PIN = 6;   // Data In

// --- Microphone Pins ---
const int I2S_MIC_SD_PIN = 20;   // Serial Data
const int I2S_MIC_SCK_PIN = 21;  // Serial Clock
const int I2S_MIC_WS_PIN = 22;   // Word Select

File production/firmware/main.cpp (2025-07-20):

#include <Arduino.h>
#include "hardware_pins.h"
#include <WiFi.h>
#include "driver/i2s.h"

// --- WiFi & Server Configuration ---
// Replace with your network credentials
const char* ssid = "YOUR_WIFI_SSID";
const char* password = "YOUR_WIFI_PASSWORD";

// Replace with your server's IP address and port
const char* server_ip = "YOUR_SERVER_IP";
const int server_port = 1234;

WiFiClient client;

// --- Audio Configuration ---
// I2S is the audio protocol we use
#define I2S_MIC_PORT I2S_NUM_0
#define I2S_SPEAKER_PORT I2S_NUM_1

// Audio sample rate and buffer size
const int SAMPLE_RATE = 16000; // 16kHz is good for voice
const int BITS_PER_SAMPLE = 16;
const int AUDIO_BUFFER_SIZE = 1024; // How many audio samples to process at a time

// --- Amplifier Power Management ---
unsigned long last_audio_received_time = 0;
const int AMP_POWER_DOWN_DELAY_MS = 200; // Turn amp off after 200ms of silence
bool is_amp_on = false;

// --- Function Prototypes ---
void setup_wifi();
void setup_i2s_microphone();
void setup_i2s_speaker();
void handle_microphone();
void handle_speaker();
void manage_amplifier();

// =================================================================
// SETUP: This runs once when you turn the power on
// =================================================================
void setup() {
  Serial.begin(115200);
  Serial.println("Booting up AR Glasses Firmware...");

  // Configure hardware pins
  pinMode(LED_BLUE_PIN, OUTPUT);
  pinMode(AMP_SHUTDOWN_PIN, OUTPUT);
  pinMode(SWITCH_BUTTON_PIN, INPUT_PULLUP);

  // Keep amplifier and LED off initially to save power
  digitalWrite(AMP_SHUTDOWN_PIN, LOW);
  digitalWrite(LED_BLUE_PIN, LOW);

  // Connect to WiFi
  setup_wifi();

  // Configure audio hardware
  setup_i2s_microphone();
  setup_i2s_speaker();

  Serial.println("Setup complete. Ready.");
}

// =================================================================
// LOOP: This runs continuously after setup
// =================================================================
void loop() {
  // Ensure we are always connected to the server
  if (!client.connected()) {
    Serial.println("Reconnecting to server...");
    if (!client.connect(server_ip, server_port)) {
      Serial.println("Connection failed. Retrying...");
      delay(1000);
      return; // Try again on the next loop
    }
    Serial.println("Connected to server.");
  }

  // Handle microphone based on button press
  handle_microphone();

  // Handle speaker based on incoming data
  handle_speaker();

  // Manage amplifier power based on speaker activity
  manage_amplifier();
}

// =================================================================
// HELPER FUNCTIONS
// =================================================================

void handle_microphone() {
  // Check if the button is currently being held down
  if (digitalRead(SWITCH_BUTTON_PIN) == LOW) {
    digitalWrite(LED_BLUE_PIN, HIGH); // Turn on LED to indicate listening

    // --- Read from Microphone and Send to Server ---
    int32_t raw_audio_buffer[AUDIO_BUFFER_SIZE];
    int16_t processed_audio_buffer[AUDIO_BUFFER_SIZE];
    size_t bytes_read = 0;

    // Read audio data from the I2S microphone
    i2s_read(I2S_MIC_PORT, &raw_audio_buffer, sizeof(raw_audio_buffer), &bytes_read, portMAX_DELAY);

    if (bytes_read > 0) {
      // Convert 32-bit samples to 16-bit
      for (int i = 0; i < bytes_read / 4; i++) {
        processed_audio_buffer[i] = (int16_t)(raw_audio_buffer[i] >> 16);
      }
      // Send the processed audio data to the server
      client.write((const uint8_t*)processed_audio_buffer, bytes_read / 2);
    }
  } else {
    // If button is not pressed, make sure LED is off
    digitalWrite(LED_BLUE_PIN, LOW);
  }
}

void handle_speaker() {
  // Check if the server has sent any audio data
  if (client.available()) {
    // If yes, turn on the amplifier if it's not already on
    if (!is_amp_on) {
      Serial.println("Audio received, turning amplifier ON.");
      digitalWrite(AMP_SHUTDOWN_PIN, HIGH);
      is_amp_on = true;
    }
    
    // Update the timer to show we just received audio
    last_audio_received_time = millis();

    // --- Play Audio on Speaker ---
    uint8_t server_audio_buffer[AUDIO_BUFFER_SIZE * 2];
    size_t bytes_written = 0;
    int bytes_received = client.read(server_audio_buffer, sizeof(server_audio_buffer));

    if (bytes_received > 0) {
      // Write the received audio data directly to the I2S speaker
      i2s_write(I2S_SPEAKER_PORT, server_audio_buffer, bytes_received, &bytes_written, portMAX_DELAY);
    }
  }
}

void manage_amplifier() {
  // If the amplifier is on, check if it's been silent for too long
  if (is_amp_on) {
    if (millis() - last_audio_received_time > AMP_POWER_DOWN_DELAY_MS) {
      Serial.println("Silence detected, turning amplifier OFF.");
      digitalWrite(AMP_SHUTDOWN_PIN, LOW);
      is_amp_on = false;
    }
  }
}


void setup_wifi() {
  Serial.print("Connecting to ");
  Serial.println(ssid);
  WiFi.begin(ssid, password);
  while (WiFi.status() != WL_CONNECTED) {
    delay(500);
    Serial.print(".");
  }
  Serial.println("");
  Serial.println("WiFi connected.");
  Serial.print("IP address: ");
  Serial.println(WiFi.localIP());
}

void setup_i2s_microphone() {
  i2s_config_t i2s_mic_config = {
    .mode = (i2s_mode_t)(I2S_MODE_MASTER | I2S_MODE_RX),
    .sample_rate = SAMPLE_RATE,
    .bits_per_sample = I2S_BITS_PER_SAMPLE_32BIT,
    .channel_format = I2S_CHANNEL_FMT_RIGHT_LEFT,
    .communication_format = I2S_COMM_FORMAT_STAND_I2S,
    .intr_alloc_flags = ESP_INTR_FLAG_LEVEL1,
    .dma_buf_count = 8,
    .dma_buf_len = 64,
    .use_apll = false,
    .tx_desc_auto_clear = false,
    .fixed_mclk = 0
  };

  i2s_pin_config_t i2s_mic_pins = {
    .bck_io_num = I2S_MIC_SCK_PIN,
    .ws_io_num = I2S_MIC_WS_PIN,
    .data_out_num = I2S_PIN_NO_CHANGE,
    .data_in_num = I2S_MIC_SD_PIN
  };

  i2s_driver_install(I2S_MIC_PORT, &i2s_mic_config, 0, NULL);
  i2s_set_pin(I2S_MIC_PORT, &i2s_mic_pins);
  i2s_set_clk(I2S_MIC_PORT, SAMPLE_RATE, I2S_BITS_PER_SAMPLE_32BIT, I2S_CHANNEL_MONO);
}

void setup_i2s_speaker() {
  i2s_config_t i2s_speaker_config = {
    .mode = (i2s_mode_t)(I2S_MODE_MASTER | I2S_MODE_TX),
    .sample_rate = SAMPLE_RATE,
    .bits_per_sample = (i2s_bits_per_sample_t)BITS_PER_SAMPLE,
    .channel_format = I2S_CHANNEL_FMT_RIGHT_LEFT,
    .communication_format = I2S_COMM_FORMAT_STAND_I2S,
    .intr_alloc_flags = ESP_INTR_FLAG_LEVEL1,
    .dma_buf_count = 8,
    .dma_buf_len = 64,
    .use_apll = false,
    .tx_desc_auto_clear = true,
    .fixed_mclk = 0
  };

  i2s_pin_config_t i2s_speaker_pins = {
    .bck_io_num = I2S_AMP_BCLK_PIN,
    .ws_io_num = I2S_AMP_LRC_PIN,
    .data_out_num = I2S_AMP_DIN_PIN,
    .data_in_num = I2S_PIN_NO_CHANGE
  };

  i2s_driver_install(I2S_SPEAKER_PORT, &i2s_speaker_config, 0, NULL);
  i2s_set_pin(I2S_SPEAKER_PORT, &i2s_speaker_pins);
}

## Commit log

2025-07-20 Apply .gitignore and re-track files
2025-07-20 Update .gitignore to track project folders
2025-07-20 Fix .gitignore to correctly track project folders
    [Glasses Battery Arm.stl, Glasses Frames.stl, Glasses PCB Arm (No PCB).stl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]
2025-07-20 Refine .gitignore to only track essential project folders
    [Glasses Battery Arm.stl, Glasses Frames.stl, Glasses PCB Arm (No PCB).stl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]
2025-07-20 Fix .gitignore and track all project files
    [Glasses Battery Arm.stl, Glasses Frames.stl, Glasses PCB Arm (No PCB).stl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]
2025-07-20 adding bill of materials :
2025-07-27 Update and rename AR Glasses BOM - Sheet1 (2).csv to AR Glasses BOM
2025-07-27 Update and rename AR Glasses BOM to AR Glasses BOM.csv
    [AR Glasses BOM.csv]
2025-07-27 updated step files
    [Glasses Battery Arm v2.step, Glasses Battery Arm.stl, Glasses Frames.stl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]
2025-07-27 updated the bom's name
    [bom.csv]
2025-08-15 Updated to connect to chatgpt directly via wifi
    [config_template.txt]
